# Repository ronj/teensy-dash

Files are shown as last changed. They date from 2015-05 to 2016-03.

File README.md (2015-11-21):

teensy-dash  
===========

Circuit / code information and documentation.
=============================================

Display
-------

The display used is ST7735 controlled 1.8" TFT. It use SPI to communicate with the uC.
The Teensy has hardware SPI which makes the communication with the display much faster than on the AVR.

*	A display tutorial including code for AVR can be found here: https://learn.adafruit.com/1-8-tft-display/
*	SPI optimization techniques can be found here: http://dorkbotpdx.org/blog/paul/display_spi_optimization;
	please note, this is for a different chipset but the same rules apply.
*	The modified Adafruit library which leverages the above techniques can be found here:
	https://github.com/PaulStoffregen/Adafruit_ST7735 and a small thread discussing this can be found here:
	https://forum.pjrc.com/threads/25045-Teensy-3-1-adafruit-1-8-18-bit-color-tft-SPI-speed
*	The base Adafruit library to draw graphics is also needed and can be found here:
	https://github.com/adafruit/Adafruit-GFX-Library

NEOPixels
---------

For shift-light and alarm indication a NEOPixel strip is used. Good documentation can be found on the
Adafruit website here: https://learn.adafruit.com/adafruit-neopixel-uberguide.

One thing to note is that the pixels need to be driven logically at supply voltage. So when using a 3.3v
uC a level shifter is needed. Comparison of level shifters can be found here: http://happyinmotion.com/?p=1247

Rotary encoder
--------------

A rotary encoder tutorial can be found here: https://learn.adafruit.com/trinket-usb-volume-knob

Custom dial faces
-----------------

In the end it may be required to make custom dial faces for the modifications done to the dash.
A very exhaustive tutorial can be found here: http://mazda626.net/topic/39309-making-custom-gauge-faces/

Inspiration
-----------

*	Digital speedometer with Arduino and 7-segment display: http://matthewcmcmillan.blogspot.nl/2014/02/arduino-digital-speedometer.html
*	MPGuino and derivatives: http://ecomodder.com/wiki/index.php/MPGuino and http://mpguino.wiseman.ee/eng

Contributing
============

1. Fork it (https://github.com/ronj/teensy-dash/fork)
2. Create your feature branch (`git checkout -b my-new-feature`)
3. Commit your changes (`git commit -am 'Add some feature'`)
4. Push to the branch (`git push origin my-new-feature`)
5. Create new Pull Request

Building teensy-dash
====================

1. Get a local copy of the repository
2. 

Testing
=======

Setting up the integration test environment
-------------------------------------------

On OSX and Linux

1. Install Cucumber
   * # sudo gem update --system
   * # sudo gem install rspec
   * # sudo gem install gherkin
   * # sudo gem install cucumber

2. Install ruby-serialport
   * # sudo gem install serialport

Running the integration tests
-----------------------------

1. Build and upload the Car Simulator (under tests\car_simulator\car_simulator.ino) Arduino Sketch for your favorite Arduino
2. Upload the sketch
3. Connect the Car Simulator as follows:
   * Pin 2 of the Arduino running the Car Simulator to the VSS input test-pin on Teensy
   * Pin 3 of the Arduino running the Car Simulator to the RPM input test-pin on Teensy
   * Connect the Arduino and Teensy grounds together

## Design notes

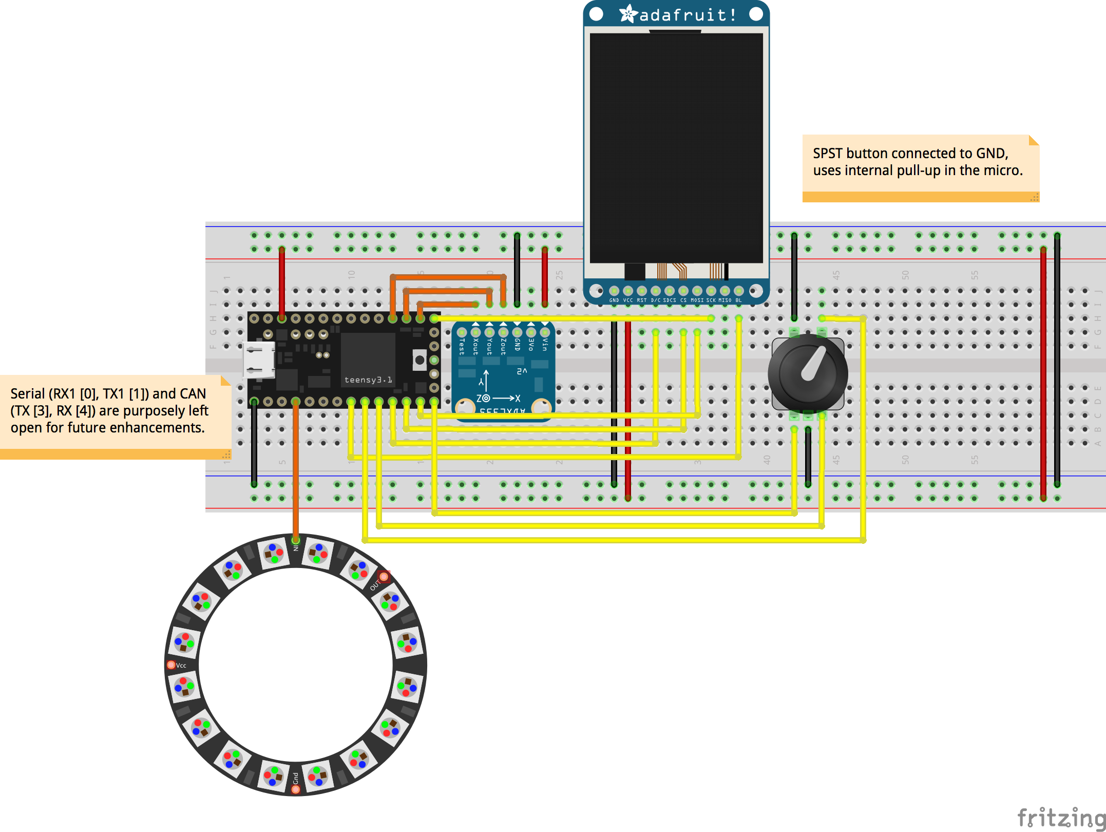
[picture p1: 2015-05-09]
documentation/schematics/dash_bb.png

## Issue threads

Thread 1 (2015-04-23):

Add support for building target binaries on Travic-CI

ronj, 2015-04-23:
Currently only the emulator is built on the Continuous Integration server. I would also like to build the target firmware, and the simulator firmware on Travis.

For this to work the Arduino and Teensy environment have to be set-up/installed when doing a CI build.

An example of building Arduino firmware can be found [here](https://github.com/kyab/travis-test-arduino).

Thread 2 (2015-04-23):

Enable CAN support

ronj, 2015-04-23:
To talk with modern vehicles CAN support would be great. The Teensy supports CAN out-of-the-box, the only hardware needed is a CAN transceiver chip.

For discussions on software and drivers see [here](https://forum.pjrc.com/threads/25101-CAN-Bus-Library-for-Teensy-3-1).

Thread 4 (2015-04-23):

Add MAC address support to TeensyPlatform

ronj, 2015-04-23:
To uniquely identify devices, and for possible future connectivity, I would like to have access to the Teensy's MAC address.

[This](http://forum.pjrc.com/threads/91-teensy-3-MAC-address) thread on PJRC describes how to read out the "read once" flash memory.

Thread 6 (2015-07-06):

Add low power mode, enter low power mode when engine is not running.

ronj, 2015-07-06:
See: https://github.com/duff2013/Snooze for example code on Teensy low power implementations.

ronj, 2015-07-07:
Teensy low power considerations
===============================

By PaulStoffregen from [this thread](https://forum.pjrc.com/threads/23660-Low-Power-quot-Green-quot-Battery-Operation-Solutions-For-The-Teensy-3/page2):

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

ronj, 2015-07-14:
Used the [Snooze library](https://github.com/duff2013/Snooze) to put the CPU to sleep when RPM equals 0. The CPU will wake up again after the RPM is nonzero.

For now there are some intricacies to the implementation, the sleep at the end of the application loop for example is mandatory and if left out the CPU will not wake from sleep. This is because then the ModelUpdateTask will not get enough time to run.

Committed in 11997eec996d601c51a4e73988f011040fb70749.

Closed 2015-07-14.

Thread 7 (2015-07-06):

Add watchdog support

ronj, 2015-07-06:

ronj, 2015-07-06:
See: https://forum.pjrc.com/threads/23570-Teensy-3-enable-Watchdog and https://forum.pjrc.com/threads/25370-Teensy-3-0-Watchdog-Timer

Closed 2015-08-06.

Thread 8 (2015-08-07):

Add OTA update support

ronj, 2015-08-07:
Because it is quite cumbersome to remove the dash every time a software update is available it would be beneficial to have over-the-air (OTA) updates.

This requires internet connectivity, provided via an ESP2866 module. Enough flash space to store the Teensy binary, and enough flash space to update the ESP's own firmware.

To get the firmware from the ESP2866 to the Teensy SWD support is needed. The Teensy does not provide SWD headers by default, but a hack is available [here](http://mcuoneclipse.com/2014/08/09/hacking-the-teensy-v3-1-for-swd-debugging/).

Using SWD for programming the Teensy means we need to support writing to SWD from the ESP. Some input can be found in [LibSWD](https://github.com/cederom/LibSWD/) and McHck's [SDW programmer](https://github.com/mchck/programmer).

I imagine the general flow to look something like:

- A new release is made via GitHub's release system.
- Release is built on Travis, and promoted after all tests have passed.
- Version info is compiled and written to version.json.
- Artifacts (teensy.bin, wifi.bin, version.json) are deployed as binaries on GitHub.
- Periodically the wifi module checks the remote version.json against the current versions.
- When a newer version is available the firmware is downloaded and flashed.
- If both a new firmware for the wifi module and the Teensy are available, the wifi module is updated first.

version.json could look something like:

    {
        "latest-wifi-firmware":
        {
            "version": "0.1.1-3f96ad",
            "url": "http://raw.githubusercontent.com/ronj/latest-wifi.bin",
            "checksum": "1949D0327F7AC7D908472DA3ECC4E87F23432C2A"
        }
    }

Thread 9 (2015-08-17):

Add support for TPMS (Tire Pressure Monitoring System)

ronj, 2015-08-17:
https://www.conrad.nl/nl/bandenspanningscontrolesysteem-tp-71b-incl-4-sensoren-1093622.html

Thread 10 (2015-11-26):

Add MQTT-SN support

ronj, 2015-11-26:
To be able to communicate the sampled data for off-board use, and to communicate with the dashboard software from outside of the car MQTT(-SN) would be a viable option.

When used in conjunction with an ESP8266 as a MQTT-SN to MQTT gateway the sampled data could be transferred to a cloud platform. Also settings could be changed on a per-device basis.

(MQTT-SN Spec)[http://mqtt.org/new/wp-content/uploads/2009/06/MQTT-SN_spec_v1.2.pdf]
(Mosca MQTT node.js server)[https://github.com/mcollina/mosca]
(MQTT-SN implementation over XBee and UDP)[https://github.com/ty4tw/MQTT-SN]
(MQTT-SN implementation over Serial)[https://bitbucket.org/MerseyViking/mqtt-sn-arduino/src/0d00d9526131?at=master]

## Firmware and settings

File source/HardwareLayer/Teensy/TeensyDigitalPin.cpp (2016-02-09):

#include "TeensyDigitalPin.h"

#include "Common/DisableInterruptContext.h"

#include "core_pins.h"

#include <array>
#include <functional>

namespace
{
    static std::array<std::function<void()>, CORE_NUM_DIGITAL> interruptFunctions;

    static void portc_interrupt2(void);
    static void portd_interrupt2(void);

    void attachInterruptVector2(enum IRQ_NUMBER_t irq, void (*function)(void))
    {
        _VectorsRam[irq + 16] = function;
    }

    void attachInterrupt2(uint8_t pin, std::function<void()> function, int mode)
    {
        volatile uint32_t *config;
        uint32_t cfg, mask;

        if (pin >= CORE_NUM_DIGITAL) return;
        switch (mode) {
          case CHANGE:  mask = 0x0B; break;
          case RISING:  mask = 0x09; break;
          case FALLING: mask = 0x0A; break;
          case LOW:     mask = 0x08; break;
          case HIGH:    mask = 0x0C; break;
          default: return;
        }
        mask = (mask << 16) | 0x01000000;
        config = portConfigRegister(pin);

        attachInterruptVector2(IRQ_PORTC, portc_interrupt2);
        attachInterruptVector2(IRQ_PORTD, portd_interrupt2);
        {
            Common::DisableInterruptContext interruptDisable;
            cfg = *config;
            cfg &= ~0x000F0000;     // disable any previous interrupt
            *config = cfg;
            interruptFunctions[pin] = function;    // set the function pointer
            cfg |= mask;
            *config = cfg;          // enable the new interrupt
        }
    }

    void detachInterrupt2(uint8_t pin)
    {
        volatile uint32_t *config;

        config = portConfigRegister(pin);
        {
            Common::DisableInterruptContext interruptDisable;
            *config = ((*config & ~0x000F0000) | 0x01000000);
            interruptFunctions[pin] = nullptr;
        }
    }

    static void portc_interrupt2(void)
    {
        // TODO: these are inefficent.  Use CLZ somehow....
        uint32_t isfr = PORTC_ISFR;
        PORTC_ISFR = isfr;
        if ((isfr & CORE_PIN22_BITMASK) && interruptFunctions[22]) interruptFunctions[22]();
        if ((isfr & CORE_PIN23_BITMASK) && interruptFunctions[23]) interruptFunctions[23]();
    }

    static void portd_interrupt2(void)
    {
        uint32_t isfr = PORTD_ISFR;
        PORTD_ISFR = isfr;
        if ((isfr & CORE_PIN2_BITMASK) && interruptFunctions[2]) interruptFunctions[2]();
        if ((isfr & CORE_PIN5_BITMASK) && interruptFunctions[5]) interruptFunctions[5]();
        if ((isfr & CORE_PIN6_BITMASK) && interruptFunctions[6]) interruptFunctions[6]();
        if ((isfr & CORE_PIN7_BITMASK) && interruptFunctions[7]) interruptFunctions[7]();
        if ((isfr & CORE_PIN8_BITMASK) && interruptFunctions[8]) interruptFunctions[8]();
        if ((isfr & CORE_PIN14_BITMASK) && interruptFunctions[14]) interruptFunctions[14]();
        if ((isfr & CORE_PIN20_BITMASK) && interruptFunctions[20]) interruptFunctions[20]();
        if ((isfr & CORE_PIN21_BITMASK) && interruptFunctions[21]) interruptFunctions[21]();
    }
}

HardwareLayer::TeensyDigitalPin::TeensyDigitalPin(const uint8_t pin)
    : TeensyDigitalPin(pin, PinType::Input)
{
}

HardwareLayer::TeensyDigitalPin::TeensyDigitalPin(const uint8_t pin, PinType type)
    : m_Pin(pin)
{
    switch (type)
    {
        case PinType::Input: pinMode(m_Pin, INPUT); break;
        case PinType::Output: pinMode(m_Pin, OUTPUT); break;
        case PinType::InputPullUp: pinMode(m_Pin, INPUT_PULLUP); break;
    }
}

HardwareLayer::TeensyDigitalPin::~TeensyDigitalPin()
{
	DisableInterrupt();
}

uint8_t HardwareLayer::TeensyDigitalPin::Read()
{
	return digitalRead(m_Pin);
}

void HardwareLayer::TeensyDigitalPin::EnableInterrupt(InterruptType mode)
{
    switch (mode)
    {
        case InterruptType::Rising: attachInterrupt2(m_Pin, OnInterrupt, RISING); break;
		case InterruptType::Falling: attachInterrupt2(m_Pin, OnInterrupt, FALLING); break;
		case InterruptType::Change: attachInterrupt2(m_Pin, OnInterrupt, CHANGE); break;
		case InterruptType::Low: attachInterrupt2(m_Pin, OnInterrupt, LOW); break;
		case InterruptType::High: attachInterrupt2(m_Pin, OnInterrupt, HIGH); break;
    }
}

void HardwareLayer::TeensyDigitalPin::DisableInterrupt()
{
	detachInterrupt2(m_Pin);
}

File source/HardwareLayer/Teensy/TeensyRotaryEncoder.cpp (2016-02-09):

#include "TeensyRotaryEncoder.h"

#include "Common/Math.h"

#include "Common/ArduinoWrapper.h"


/* Rotary encoder handler for arduino. v1.1
 *
 * Copyright 2011 Ben Buxton. Licenced under the GNU GPL Version 3.
 * Contact: bb@cactii.net
 *
 * A typical mechanical rotary encoder emits a two bit gray code
 * on 3 output pins. Every step in the output (often accompanied
 * by a physical 'click') generates a specific sequence of output
 * codes on the pins.
 *
 * There are 3 pins used for the rotary encoding - one common and
 * two 'bit' pins.
 *
 * The following is the typical sequence of code on the output when
 * moving from one step to the next:
 *
 *   Position   Bit1   Bit2
 *   ----------------------
 *     Step1     0      0
 *      1/4      1      0
 *      1/2      1      1
 *      3/4      0      1
 *     Step2     0      0
 *
 * From this table, we can see that when moving from one 'click' to
 * the next, there are 4 changes in the output code.
 *
 * - From an initial 0 - 0, Bit1 goes high, Bit0 stays low.
 * - Then both bits are high, halfway through the step.
 * - Then Bit1 goes low, but Bit2 stays high.
 * - Finally at the end of the step, both bits return to 0.
 *
 * Detecting the direction is easy - the table simply goes in the other
 * direction (read up instead of down).
 *
 * To decode this, we use a simple state machine. Every time the output
 * code changes, it follows state, until finally a full steps worth of
 * code is received (in the correct order). At the final 0-0, it returns
 * a value indicating a step in one direction or the other.
 *
 * It's also possible to use 'half-step' mode. This just emits an event
 * at both the 0-0 and 1-1 positions. This might be useful for some
 * encoders where you want to detect all positions.
 *
 * If an invalid state happens (for example we go from '0-1' straight
 * to '1-0'), the state machine resets to the start until 0-0 and the
 * next valid codes occur.
 *
 * The biggest advantage of using a state machine over other algorithms
 * is that this has inherent debounce built in. Other algorithms emit spurious
 * output with switch bounce, but this one will simply flip between
 * sub-states until the bounce settles, then continue along the state
 * machine.
 * A side effect of debounce is that fast rotations can cause steps to
 * be skipped. By not requiring debounce, fast rotations can be accurately
 * measured.
 * Another advantage is the ability to properly handle bad state, such
 * as due to EMI, etc.
 * It is also a lot simpler than others - a static state table and less
 * than 10 lines of logic.
 */


/*
 * The below state table has, for each state (row), the new state
 * to set based on the next encoder output. From left to right in,
 * the table, the encoder outputs are 00, 01, 10, 11, and the value
 * in that position is the new state to set.
 */

#define R_START 0x0

#ifdef HALF_STEP
// Use the half-step state table (emits a code at 00 and 11)
#define R_CCW_BEGIN 0x1
#define R_CW_BEGIN 0x2
#define R_START_M 0x3
#define R_CW_BEGIN_M 0x4
#define R_CCW_BEGIN_M 0x5
const unsigned char ttable[6][4] = {
  // R_START (00)
  {R_START_M,            R_CW_BEGIN,     R_CCW_BEGIN,  R_START},
  // R_CCW_BEGIN
  {R_START_M | DIR_CCW, R_START,        R_CCW_BEGIN,  R_START},
  // R_CW_BEGIN
  {R_START_M | DIR_CW,  R_CW_BEGIN,     R_START,      R_START},
  // R_START_M (11)
  {R_START_M,            R_CCW_BEGIN_M,  R_CW_BEGIN_M, R_START},
  // R_CW_BEGIN_M
  {R_START_M,            R_START_M,      R_CW_BEGIN_M, R_START | DIR_CW},
  // R_CCW_BEGIN_M
  {R_START_M,            R_CCW_BEGIN_M,  R_START_M,    R_START | DIR_CCW},
};
#else
// Use the full-step state table (emits a code at 00 only)
#define R_CW_FINAL 0x1
#define R_CW_BEGIN 0x2
#define R_CW_NEXT 0x3
#define R_CCW_BEGIN 0x4
#define R_CCW_FINAL 0x5
#define R_CCW_NEXT 0x6

const unsigned char ttable[7][4] = {
  // R_START
  {R_START,    R_CW_BEGIN,  R_CCW_BEGIN, R_START},
  // R_CW_FINAL
  {R_CW_NEXT,  R_START,     R_CW_FINAL,  R_START | DIR_CW},
  // R_CW_BEGIN
  {R_CW_NEXT,  R_CW_BEGIN,  R_START,     R_START},
  // R_CW_NEXT
  {R_CW_NEXT,  R_CW_BEGIN,  R_CW_FINAL,  R_START},
  // R_CCW_BEGIN
  {R_CCW_NEXT, R_START,     R_CCW_BEGIN, R_START},
  // R_CCW_FINAL
  {R_CCW_NEXT, R_CCW_FINAL, R_START,     R_START | DIR_CCW},
  // R_CCW_NEXT
  {R_CCW_NEXT, R_CCW_FINAL, R_CCW_BEGIN, R_START},
};
#endif

/*
 * Constructor. Each arg is the pin number for each encoder contact.
 */
Rotary::Rotary(char _pin1, char _pin2) {
  // Assign variables.
  pin1 = _pin1;
  pin2 = _pin2;
  // Set pins to input.
  pinMode(pin1, INPUT);
  pinMode(pin2, INPUT);
#ifdef ENABLE_PULLUPS
  digitalWrite(pin1, HIGH);
  digitalWrite(pin2, HIGH);
#endif
  // Initialise state.
  state = R_START;
}

unsigned char Rotary::process() {
  // Grab state of input pins.
  unsigned char pinstate = (digitalRead(pin2) << 1) | digitalRead(pin1);
  // Determine new state from the pins and state table.
  state = ttable[state & 0xf][pinstate];
  // Return emit bits, ie the generated event.
  return state & 0x30;
}





HardwareLayer::TeensyRotaryEncoder::TeensyRotaryEncoder()
    : m_Encoder(8, 12)
{
}

bool HardwareLayer::TeensyRotaryEncoder::NewValueAvailable()
{
    m_CurrentEncoderValue = m_Encoder.process();
    return (m_CurrentEncoderValue != m_PreviousEncoderValue);
}

int8_t HardwareLayer::TeensyRotaryEncoder::GetDirection()
{
    return m_CurrentEncoderValue;
}

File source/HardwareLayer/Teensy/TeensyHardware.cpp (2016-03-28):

#include "TeensyHardware.h"

HardwareLayer::TeensyHardware::TeensyHardware()
	: m_XPin(A0)
	, m_YPin(A1)
	, m_ZPin(A2)
	, m_BacklightPin(6)
	, m_BatteryVoltagePin(22)
	, m_VSSPin(23, PinType::InputPullUp)
	, m_InjectorPin(21, PinType::Input)
	, m_ParkingSensorPin(5, PinType::Input)
	, m_ButtonPin(7, PinType::InputPullUp)
	, m_AccelerometerDriver(m_XPin, m_YPin, m_ZPin)
	, m_LedDriver(2)
	, m_RotaryEncoder()
{
	m_Platform.Init();
	m_BacklightPin.Write(0);
}

HardwareLayer::Platform& HardwareLayer::TeensyHardware::GetPlatform()
{
	return m_Platform;
}

HardwareLayer::AccelerometerDriver& HardwareLayer::TeensyHardware::GetAccelerometerDriver()
{
	return m_AccelerometerDriver;
}

HardwareLayer::DisplayDriver& HardwareLayer::TeensyHardware::GetDisplayDriver()
{
	return m_DisplayDriver;
}

HardwareLayer::LedDriver& HardwareLayer::TeensyHardware::GetLedDriver()
{
	return m_LedDriver;
}

HardwareLayer::Timer& HardwareLayer::TeensyHardware::GetTimer()
{
	return m_Timer;
}

HardwareLayer::RotaryEncoder& HardwareLayer::TeensyHardware::GetRotaryEncoder()
{
	return m_RotaryEncoder;
}

HardwareLayer::DigitalPin& HardwareLayer::TeensyHardware::GetVSSPin()
{
    return m_VSSPin;
}

HardwareLayer::DigitalPin& HardwareLayer::TeensyHardware::GetInjectorPin()
{
    return m_InjectorPin;
}

HardwareLayer::DigitalPin& HardwareLayer::TeensyHardware::GetParkingSensorPin()
{
	return m_ParkingSensorPin;
}

HardwareLayer::DigitalPin& HardwareLayer::TeensyHardware::GetButtonPin()
{
	return m_ButtonPin;
}

HardwareLayer::FrequencyCounter& HardwareLayer::TeensyHardware::GetRPMFrequencyCounter()
{
	return m_RPMFrequencyCounter;
}

const HardwareLayer::AnalogPin& HardwareLayer::TeensyHardware::GetBatteryVoltagePin()
{
    return m_BatteryVoltagePin;
}

HardwareLayer::AnalogPin& HardwareLayer::TeensyHardware::GetBacklightPin()
{
    return m_BacklightPin;
}

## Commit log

2015-04-12 Initial commit
    already quite some working functionality
    [Configuration.h, dash.fzz]
2015-04-12 Fix build
    … already broke build on first commit *sigh*
2015-04-12 Added Pitch and Roll models and fixed Z axis calibration
2015-04-15 Added HippoMocks mocking framework
2015-04-15 Fixed compiler warnings in Pitch- and RollModel
2015-04-15 Implemented RAII interrupt disable/enable class
2015-04-15 Used RAII interrupt context in SpeedModel
2015-04-19 Moved some magic values over to Configuration class, added cucumber test scenario, factored out PulseCounter
    [Configuration.h]
2015-04-20 Increased speed of serial port, made simulator more robust first time after power-up, refactored integration tests and added remote CPU restart command
    [dash.fzz]
2015-04-21 Added test for SpeedModel and fixed some bugs that came to light
    [Configuration.h]
2015-04-22 Add logging of reset reason
    [TeensyHardware.cpp]
2015-04-22 Disable Arduino specific calls in PeripheralLayer for now, to let CI build pass
2015-04-24 Assigned pin number to VSS pin, fixes build
    [TeensyHardware.cpp]
2015-04-24 Fix stupid bug in TeensyDigitalPin, was not assigning the static pointer to class _and_ not checking for nullptr.
    [TeensyDigitalPin.cpp]
2015-04-26 Added SerialEventSource to control the device via serial commands; this is used in the integration tests
2015-04-30 Added RPM pin and associated with PulseCounter; for this TeensyDigitalPin and DigitalPin interface needed to be refactored.
2015-05-02 Fix an off-by-one error in gear calculation; seriously need to add a unit test for CalculatedGearModel
2015-05-03 We have three screens now: speed/rpm, gear and acceleration
2015-05-09 Updated fritzing diagram, added datasheets of some components.
    [dash.fzz]
2015-05-09 Fixed a pin assignment error in the fritzing diagram. SPI to TFT was not properly connected.
    [dash.fzz]
2015-05-09 Made accelerometer pin-assignment in line with fritzing diagram.
2015-05-09 Shifted more pins around.
    [dash.fzz]
2015-05-09 Moved backlight of TFT from VCC to PWM pin of Teensy according to fritzing diagram.
2015-06-23 Made pulses per RPM configurable. Some cars have trigger arrangements that pulse multiple times per engine revolution (e.g. Peugeot has 62-2 trigger configuration on the flywheel).
    [Configuration.h]
2015-06-23 Change gear configuration to 1.6 MA gearbox i.s.o. GTi6 BE gearbox.
2015-06-24 Re-instate virtual functions in Configuration class to enable mocking.
    [Configuration.h]
2015-06-27 Added document about voltage transients in an automotive environment.
2015-06-27 Configure internal pull-up of Teensy to eliminate external pull-up resistor in optocoupler output for VSS.
2015-06-28 Added support for battery voltage measurement.
2015-07-02 Change formatting of VoltageModel.
2015-07-07 Updated voltage divider for 12 volt car battery/charging voltage measurements (e.g. 13.8v to 3.3v with a safety margin).
2015-07-08 Remove pulses per RPM parameter, there is no need for it. Also "virtualize" Configuration methods to be able to mock them.
    [Configuration.h]
2015-07-08 Forgot to stage some lines, I should really make feature branches in the future!
2015-07-09 Relaxed the watchdog a bit more. We need to kick the dog every 3 to 5 seconds approximately. This gives us time to boot, but also a fast response time in case of a problem.
2015-07-11 Added sensor-to-view chain for trip computer. - Factored out accumulation of wheel ticks in a separate model, such that trip and speed models both can use it. - Added TipComputerModel, which is a bit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
2015-07-11 Some changes to Fritzing diagram. Added optocoupler for VSS input from car.
    [dash.fzz]
2015-07-13 Implemented basic power management. When RPM is 0, the CPU will go into a deep sleep mode consuming minimal energy. It will wake up every two seconds to check for an RPM signal and go to sleep again 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
    [TeensyHardware.cpp]
2015-07-13 Made both low power mode and watchdog active. WARNING: moved watchdog initialization to external library Snooze. Should find another way to initialize watchdog or make Snooze code internal.
2015-07-14 Reverted update frequency of SpeedModel back to 1 Hz, 2 Hz caused erratic and incorrect readings.
2015-07-14 Fixed incorrect accumulation of wheel ticks in SpeedModel after factoring out the PulseCounter.
2015-07-14 Added Query method to Views to be able to ask for their current value from the integration test framework.
2015-07-28 Shuffled documentation around a bit.
    [dash.fzz]
2015-07-30 Made gear ratios fractions for more precision and try other final drive ratio.
2015-08-04 Updated integration tests. - Added new scenario for gear screen - Moved serial port names to config file
2015-08-05 Disable VSS interrupt when going into sleep mode, this fixes an issue with spurious wake-ups and waking up with incorrect clock settings.
    [TeensyDigitalPin.cpp]
2015-08-06 Implemented end-to-end chain for parking distance control (PDC).
2015-08-15 Add logging to power management methods and remove Idle method.
2015-08-16 Small modifications to Shiftlight. Faster and brighter alarm, when RPM goes down LEDs are cleared.
2015-09-16 Added InjectorPin to HardwareLayer. Now we can connect the pin to the PulseDuration counter for measurement of fuel consumption.
2015-09-16 Hook up ApplicationLayer::InjectorModel to the Injector DurationCounter in PeripheralLayer.
    [Configuration.h]
2015-09-24 Compensate for injector mechanical delay. Make InjectorModel available to TripComputer.
    [Configuration.h]
2015-11-21 Updated schematic in Fritzing diagram. Breadboard suffered from this action but schematic is more clear.
    [dash.fzz]
2015-11-24 Added initial effort for a GenericModel that uses a third order polynomial to calculate a sensor value. This can be useful for generic temperature and pressure sensors.
2015-11-24 Fixed some more warnings.
    [TeensyHardware.cpp]
2015-11-25 While toolchain not yet operational in new style, temporarily switch back to force compiler.
2015-12-03 Added initial TirePressure view and model.
2015-12-12 Draw tire temperature besides pressure.
2016-02-09 Update gearbox and injector parameters to GTi6 (XU10J4RS).
2016-02-09 Added "ThreeRowView" (which can be generalized to NRowView). And made a screen with Voltage information. Adapted the representation of Voltage readings.
2016-02-09 Added push-button support and changed implementation of RotaryEncoder.
2016-02-10 Refactor led subsystem. Give led's a specific hardware layer interface. Introduce PatternPlayer concept; should eventually control led's and clients can set a "pattern" i.e. slow-blink, fill, fill-wi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
